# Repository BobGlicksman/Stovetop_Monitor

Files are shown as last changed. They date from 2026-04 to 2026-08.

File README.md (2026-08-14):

# Stovetop_Monitor.
## Overview.
The Stovetop Monitor project provides standoff, non-invasive monitoring of a stovetop with algorithms that 
determine if one or more burners are left on unintentionally.  An infrared (IR) temperature sensor is used to detect, 
categorize and track the IR radiation from the stovetop.  

## Purpose.
A stovetop burner that is accidentally left on presents a fire hazard.  Busy/distracted people, as well as elderly people 
who are becoming forgetful, can accidentally leave a stovetop burner on, unattended.  In the worst case, this can lead to 
a fire hazard and burn down the house as well as risking lives.  In less than the worst case, it can lead to damage to 
the stove and/or cookware.

## Solution.
The Stovetop Monitor uses a Melexis MLX90614 IR temperature sensor to continuously monitor both the ambient air temperature 
and the IR temperature of the stovetop.  A custom designed 3D printed enclosure houses the sensor and associated electronics.
The electronics mount underneath a cabinet that is above and off to the side of the stovetop.  The enclosure mounts the IR
temperature sensor so that it looks down at the stovetop at a 45 degree angle.  The entire stovetop is within the sensor's
field of view.

A Particle Photon 2 WiFi enabled microcontroller reads and processes sensor data.  The algorithm attempts to categorize what
is happening on the stovetop as Normal (burners are off), Warming (one or more burners on low), Cooking (one or more burners
on medium - high), or Burning (unusually high IR temperature reading).  Each of these stovetop states has an associated timeout,
beyond which it is assumed that the stovetop has been left on unattended.  After a timeout, a visual and audible alarm sounds.  A
remote alarm on a smartphone may also be configured using the Particle Cloud, Particle Webhooks and Pushover app capabilities.
An Android smartphone app is also included with this project, allowing a user to remotely monitor the status of their stovetop
an the ability to remotely reset any alarm in process.

See the "Stovetop_Monitor_Overview_and_Theory_of_Operation" document in this Repository for further details.

## Contents of this Repository.
### Top Level.
- "README.md": this document.
- "Terms_of_Use_License_and_Disclaimer":  You must agree to the contents of this document in order to use the material
    in this Repository.
- "Stovetop_Monitor_Overview_and_Theory_of_Operation":  This document provides an overview of the project.  It contains
    the project requirements, architecture, and theory of operation.
### Documents Folder.
- "Stovetop_Monitor_Build_and_Install_Manual":  Instructions for building and installing the Stovetop Monitor hardware
    and software.
- "Stovetop_Monitor_User_Manual":  Instructions for using the Stovetop Monitor, both locally and remotely.
### Hardware Folder.
- 3D CAD .stl files for the 3D printed enclosure and top mounting bracket.
- Fusion 360 .f3d file to allow modifying the enclosure design in Fusion 360 CAD software.
- MLX90614 IR temperature sensor datasheet.
- "A NOTE ABOUT PIEZO BUZZERS.txt": Options for the piezo buzzer that provides the audible alarm capability of the Stovetop Monitor.
### Software Folder.
#### AI2_App.
MIT App Inventor 2 source code and .apk installation file for the Android App that is part of this project.
#### StovetopMonitor.
Source code, libraries and helper files for the Photon 2 microcontroller.
#### Webhook.
JSON representation of the Particle Webhook for sending remote alarms using Pushover.

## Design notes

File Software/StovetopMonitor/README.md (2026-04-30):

# Stovetop_Test

This firmware project was created using [Particle Developer Tools](https://www.particle.io/developer-tools/) and is compatible with all [Particle Devices](https://www.particle.io/devices/).

Feel free to replace this README.md file with your own content, or keep it for reference.

## Table of Contents
- [Introduction](#introduction)
- [Prerequisites To Use This Template](#prerequisites-to-use-this-repository)
- [Getting Started](#getting-started)
- [Particle Firmware At A Glance](#particle-firmware-at-a-glance)
  - [Logging](#logging)
  - [Setup and Loop](#setup-and-loop)
  - [Delays and Timing](#delays-and-timing)
  - [Testing and Debugging](#testing-and-debugging)
  - [GitHub Actions (CI/CD)](#github-actions-cicd)
  - [OTA](#ota)
  - [Assets](#assets)
  - [Environment](#environment)
- [Support and Feedback](#support-and-feedback)
- [Version](#version)

## Introduction

For an in-depth understanding of this project template, please refer to our [documentation](https://docs.particle.io/firmware/best-practices/firmware-template/).

## Prerequisites To Use This Repository

To use this software/firmware on a device, you'll need:

- A [Particle Device](https://www.particle.io/devices/).
- Windows/Mac/Linux for building the software and flashing it to a device.
- [Particle Development Tools](https://docs.particle.io/getting-started/developer-tools/developer-tools/) installed and set up on your computer.
- Optionally, a nice cup of tea (and perhaps a biscuit).

## Getting Started

1. While not essential, we recommend running the [device setup process](https://setup.particle.io/) on your Particle device first. This ensures your device's firmware is up-to-date and you have a solid baseline to start from.

2. If you haven't already, open this project in Visual Studio Code (File -> Open Folder). Then [compile and flash](https://docs.particle.io/getting-started/developer-tools/workbench/#cloud-build-and-flash) your device. Ensure your device's USB port is connected to your computer.

3. Verify the device's operation by monitoring its logging output:
    - In Visual Studio Code with the Particle Plugin, open the [command palette](https://docs.particle.io/getting-started/developer-tools/workbench/#particle-commands) and choose "Particle: Serial Monitor".
    - Or, using the Particle CLI, execute:
    ```
    particle serial monitor --follow
    ```

4. Uncomment the code at the bottom of the cpp file in your src directory to publish to the Particle Cloud! Login to console.particle.io to view your devices events in real time.

5. Customize this project! For firmware details, see [Particle firmware](https://docs.particle.io/reference/device-os/api/introduction/getting-started/). For information on the project's directory structure, visit [this link](https://docs.particle.io/firmware/best-practices/firmware-template/#project-overview).

## Particle Firmware At A Glance

### Logging

The firmware includes a [logging library](https://docs.particle.io/reference/device-os/api/logging/logger-class/). You can display messages at different levels and filter them:

```
Log.trace("This is trace message");
Log.info("This is info message");
Log.warn("This is warn message");
Log.error("This is error message");
```

### Setup and Loop

Particle projects originate from the Wiring/Processing framework, which is based on C++. Typically, one-time setup functions are placed in `setup()`, and the main application runs from the `loop()` function.

For advanced scenarios, explore our [threading support](https://docs.particle.io/firmware/software-design/threading-explainer/).

### Delays and Timing

By default, the setup() and loop() functions are blocking whilst they run, meaning that if you put in a delay, your entire application will wait for that delay to finish before anything else can run. 

For techniques that allow you to run multiple tasks in parallel without creating threads, checkout the code example [here](https://docs.particle.io/firmware/best-practices/firmware-template/).

(Note: Although using `delay()` isn't recommended for best practices, it's acceptable for testing.)

### Testing and Debugging

For firmware testing and debugging guidance, check [this documentation](https://docs.particle.io/troubleshooting/guides/build-tools-troubleshooting/debugging-firmware-builds/).

### GitHub Actions (CI/CD)

This project provides a YAML file for GitHub, automating firmware compilation whenever changes are pushed. More details on [Particle GitHub Actions](https://docs.particle.io/firmware/best-practices/github-actions/) are available.

### OTA

To learn how to utilize Particle's OTA service for device updates, consult [this documentation](https://docs.particle.io/getting-started/cloud/ota-updates/).

Test OTA with the 'Particle: Cloud Flash' command in Visual Studio Code or the CLI command 'particle flash'!

This firmware supports binary assets in OTA packages, allowing the inclusion of audio, images, configurations, and external microcontroller firmware. More details are [here](https://docs.particle.io/reference/device-os/api/asset-ota/asset-ota/).

### Assets

To include assets in your OTA bundle, create an `assets` folder in your project root and place your files there. These can include audio files, images, configuration files, or firmware for external microcontrollers.

To enable asset OTA, uncomment the following line in `project.properties`:
```
assetOtaDir=assets
```

See the [Asset OTA documentation](https://docs.particle.io/reference/device-os/api/asset-ota) for more details.

### Environment

To bundle environment variables with your firmware, create an `env.json` file in your project root. Uncomment the following line in `project.properties` to enable it:
```
env=env.json
```

See the [Environment documentation](https://docs.particle.io/reference/device-os/api/environment) for more details.

## Support and Feedback

For support or feedback on this template or any Particle products, please join our [community](https://community.particle.io)!

## Version

Template version 1.0.3

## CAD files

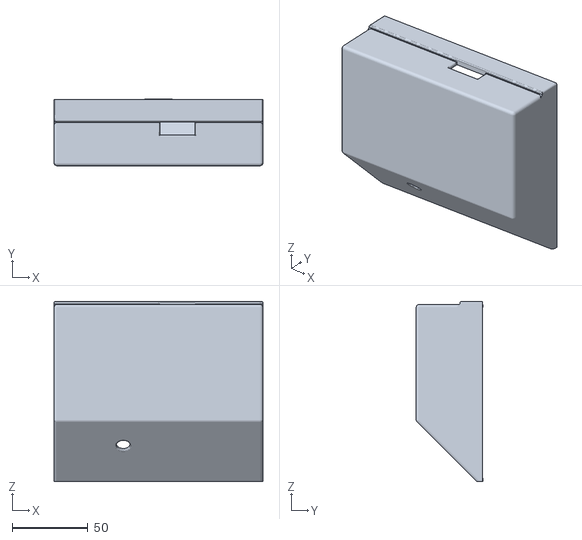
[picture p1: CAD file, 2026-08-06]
Hardware/stove monitor box.stl
138.0 x 44.0 x 119.0

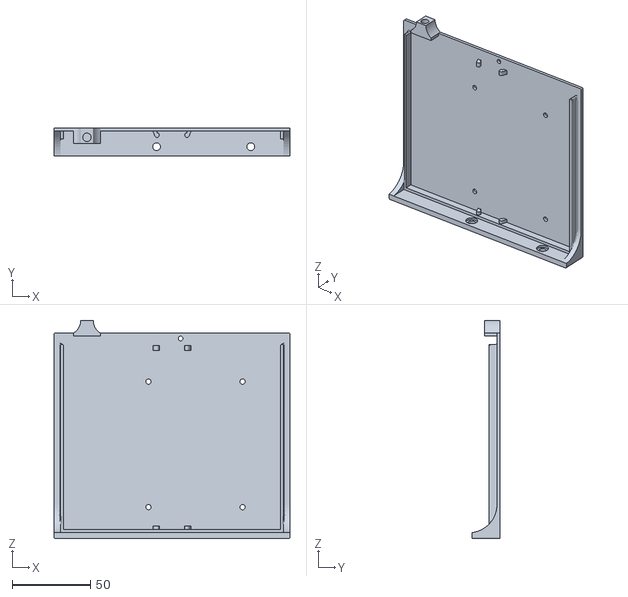
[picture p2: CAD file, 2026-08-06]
Hardware/stove monitor mount.stl
150.4 x 18.0 x 139.0

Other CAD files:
Hardware/stove monitor v34.f3d

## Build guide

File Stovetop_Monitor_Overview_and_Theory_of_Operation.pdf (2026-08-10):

# Stovetop Monitor Overview and Theory of Operation

By: Jim Schrempp and Bob Glicksman; v1.1, 8/10/2026

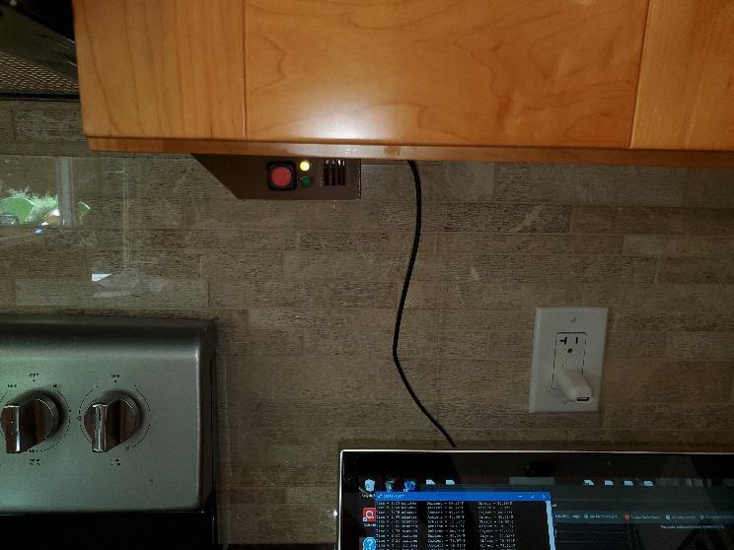
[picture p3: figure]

© 2026 Team Practical Projects, Bob Glicksman, and Jim Schrempp. All rights reserved.

NOTICE: Use of this document is subject to the terms of use described in the document
“Terms_of_Use_License_and_Disclai mer” that is included in this release package. This document can be found at:

https://github.com/TeamPracticalProjects/Stovetop_Monitor/tree/main/Documents/Terms_of_Use_License_and_Dis claimer.pdf

© 2026, Team Practical Projects, Jim Schrempp and Bob Glicksman; all rights reserved. Subject to “Terms of Use, License and Disclosure”

TABLE OF CONTENTS.

TABLE OF CONTENTS. | 1
DOCUMENT OVERVIEW. | 2
PROBLEM STATEMENT AND SOLUTION OVERVIEW. | 2
STOVETOP MONITOR SYSTEM OVERVIEW. | 3
Electronics. | 4
Particle Cloud. | 5
Pushover. | 5
Stovetop Monitor App. | 6
STOVETOP MONITOR THEORY OF OPERATION. | 6

DOCUMENT OVERVIEW.

This document provides an overview of the Stovetop Monitor project from Team Practical Projects. The Stovetop Monitor monitors the state of a stovetop and alarms if it senses that a burner is turned on for too long.

# PROBLEM STATEMENT AND SOLUTION

OVERVIEW.

A stovetop burner that is accidentally left on presents a fire hazard. Busy/distracted people, as well as elderly people who are becoming forgetful, can accidentally leave a stovetop burner on, unattended. In the worst case, this can lead to a fire hazard and burn down the house as well as risking lives. In less than the worst case, it can lead to damage to the stove and/or cookware.

There are few, if any, stovetop/ovens on the market that provide remote access via an app. In general, interconnected stoves have apps that can monitor and control an oven but do not have a similar capability vis-a-vis the stovetop burners. These apps are aimed at remote control of baking in the oven and it is assumed that cooking on the stovetop will always be attended.

Modern stovetop/ovens tend not to have mechanical controls. Rather, they are electronically controlled via an embedded microcontroller. This means that the status of the stovetop burners cannot be monitored nor can they be controlled remotely by hacking into electro-mechanical switches. An external solution - one that does not modify the stovetop/oven in any way - needs to be developed.

The Stovetop Monitor project provides standoff, non-invasive monitoring of a stovetop with algorithms that determine if one or more burners are left on unintentionally. An infrared (IR) temperature sensor is used to detect, categorize and track the IR radiation from the stovetop. The difference between the IR temperature measurement from the stovetop area and the ambient temperature is used to classify the current operation of the stovetop into:

- WARMing
- COOKing
- BURNing

Each of these stovetop states is pre-assigned a time limit above which it can be assumed to exceed normal stovetop operation. When the time limit is exceeded in any of these states, an ALARM is indicated and the user is notified to take action to attend to the situation. The temperature (temperature difference) and timeout thresholds that ultimately trigger alarms are contained in a separate file so that installation-specific values can be used. The Stovetop Monitor allows a computer running a serial monitor to attach and record IR and ambient temperature profiles for various test conditions in order to calibrate the system for the specific type of stovetop and sensor position for any specific installation.

The specific calibration values released with this project were empirically determined for an electric glasstop stove and a sensor that is mounted under a cabinet that is above and off to the right side of the stovetop. The sensor has a 90 degree field of view (FOV) and looks down at the stovetop at a 45 degree angle. The one sensor therefore covers the state of all of the burners on a stovetop. In addition to electric stovetops, this project should work well with gas burner stovetops. This project is not expected to be useful for induction stovetops, which turn off automatically when a pan is removed from a burner.

The standoff and non-invasive nature of this problem solution is, necessarily, imperfect. We have opted to err on the side of false positives, as the consequence of too many alarms is annoying but the consequences of missed alarm conditions can be very severe.

STOVETOP MONITOR SYSTEM OVERVIEW.

Figure 1 presents a system diagram for the Stovetop Monitor project.

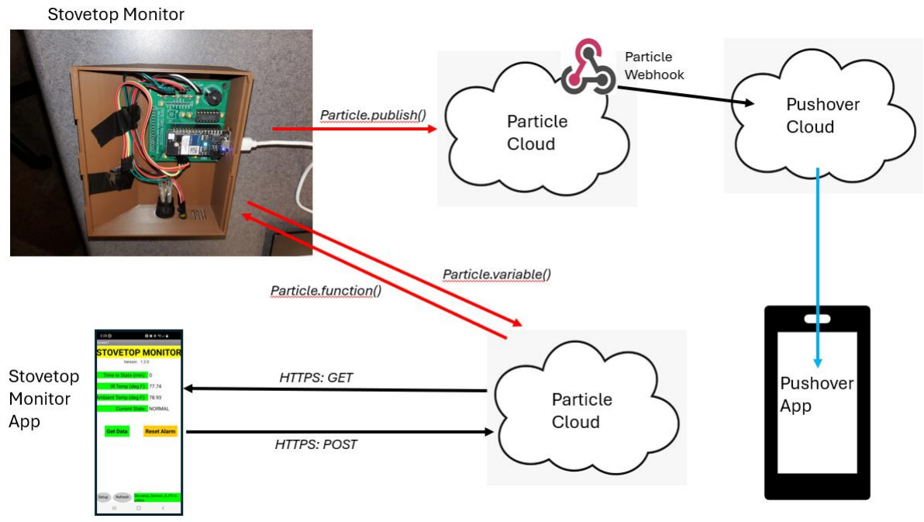
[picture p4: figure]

Figure 1. Stovetop Monitor System Overview.

The Stovetop Monitor electronics uses an IR temperature sensor to measure the infrared energy given off from the stovetop, as well as the ambient temperature at the sensor. A WiFi enabled microcontroller¹ uses these measurements to determine the state of the stovetop and to track the time in the current state. If the time in the current state exceeds a predetermined value, an alarm is generated.

Alarm events are published to the Particle Cloud. A webhook in the Particle Cloud subscribes to alarm events and uses the Pushover API to generate a push notification on the user’s smartphone.

An optional Android app uses the Particle Cloud API to read out the data from the electronics so that the user can determine the status of the Stovetop Monitor at any time. The App also allows the user to remotely reset any alarm that is in process.

Electronics.

The Stovetop Monitor electronics is based upon a Melexis MLX-60914 IR temperature sensor; see:
https://www.melexis.com/en/documents/documentation/datasheets/datasheet-mlx90614

We chose to use a breadboard friendly module that incorporates this sensor:

https://www.amazon.com/dp/B0B63K5V7T?ref=ppx_yo2ov_dt_b_fed_asin_title

The module includes the sensor itself, a low dropout voltage regulator, and I2C pullup resistors. The low dropout voltage regulator allows the module to operate with both 5 volt and 3.3 volt systems.

A Particle² Photon 2 microcontroller module forms the “brains” of the electronics. The Photon 2 is WiFi enabled and tightly integrated with the Particle Cloud. The Particle Cloud provides Internet connectivity to the electronics which is necessary for remote alarming and remote statusing of the system.

The sensor connects to the Photon 2 via the I2C bus. The electronics also contains level shifter circuitry that allows the Photon 2 to control a green, yellow and red LED and a piezo buzzer, and connects a pushbutton switch as a digital input to the Photon 2. The electronic components are mounted on the printed circuit board that was developed as part of an earlier Team practical Projects project, see:

https://github.com/TeamPracticalProjects/MN_ACL/tree/master/Hardware/PC_board

1 Particle Photon 2

2 Particle.io

Only part of the capability of this printed circuit board is used on this project. See the “Build and Install Manual” for this project for details.

The complete electronics are housed in a custom 3D printed enclosure with an accompanying 3D printed mounting bracket:

https://github.com/TeamPracticalProjects/Stovetop_Monitor/tree/main/Hardware

Particle Cloud.

The Particle Cloud provides Internet connectivity for this project:

- The firmware³
running on the Photon 2 publishes alarm events to the Particle Cloud. A custom webhook⁴
installed in the user’s Particle account subscribes to these event publications and uses the Pushover⁵ API to generate a push notification on the user’s smartphone. The Pushover notification serves as a remote alarm notification that is available to the user anywhere that they have smart phone connectivity.
- The firmware running on the Photon 2 exposes several global variables to the Particle Cloud, including the firmware version, the current stovetop state, the latest IR temperature reading, the latest ambient temperature reading, and the accumulated time in the current stovetop state.
- The firmware running on the Photon 2 provides remote calling of a function in the firmware that resets any alarm that is in process.

Pushover.

Pushover is a commercial service for adding push notifications to any smartphone. The user must install the Pushover app on their smartphone (available for both iOS and Android). The app requires a one time in-app fee of $5 and supports up to 10,000 push notifications per month at no additional cost. The Pushover app allows the user to select from a range of priority values and a large set of notification sounds.

3 https://github.com/TeamPracticalProjects/Stovetop_Monitor/tree/main/Software/StovetopMonitor

4 https://github.com/TeamPracticalProjects/Stovetop_Monitor/tree/main/Software/Webhook

5 https://pushover.net/

Stovetop Monitor App.

A Stovetop Monitor App⁶
is provided with this project. This App allows the user to monitor the status of the Stovetop Monitor and to remotely reset any alarm that is in process. The App is written in MIT App Inventor 2 has been built and tested for Android⁷ devices. The intention is that the user can respond to a remote alarm by viewing the status of the system in order to gain a better understanding of the nature of the alarm and the urgency of a response. However, the non-invasive nature of this project does not provide a means for the user to remotely control the stovetop itself. If a burner has been left on unintentionally, it will need to be manually turned off at the stovetop itself.

The user can, alternatively, use the Particle Console to monitor the stovetop and reset alarms. See the “Stovetop Monitor User Manual” for further details.

STOVETOP MONITOR THEORY OF OPERATION.

The firmware running on the Photon 2 microcontroller reads data from the Melexis sensor once every 15 seconds. This time interval was selected because of the large thermal lag of the stovetop. More frequent readings just add noise to the algorithm, while meaningful temperature changes occur more slowly.

Each reading from the sensor updates:
- The current IR temperature measurement.
- The current ambient sensor temperature measurement.

These readings are used to update the state of the system, per the state diagram shown in figure 2, below.

Note that the Melexis sensor occasionally and randomly returns an erroneous reading of 1899.59 degrees F on either the IR temperature or the ambient temperature. The reason for these erroneous readings is not known, but we think it is due to the fact that the Melexis sensor uses a special subset of the I2C protocol that powers down automatically and needs to occasionally wake-up when queried for new data. The firmware detects and disregards these erroneous readings.

6 https://github.com/TeamPracticalProjects/Stovetop_Monitor/tree/main/Software/AI2_App

7
In principle, this app can be built for iOS and deployed via the Apple App Store; However, we have not tested this deployment.

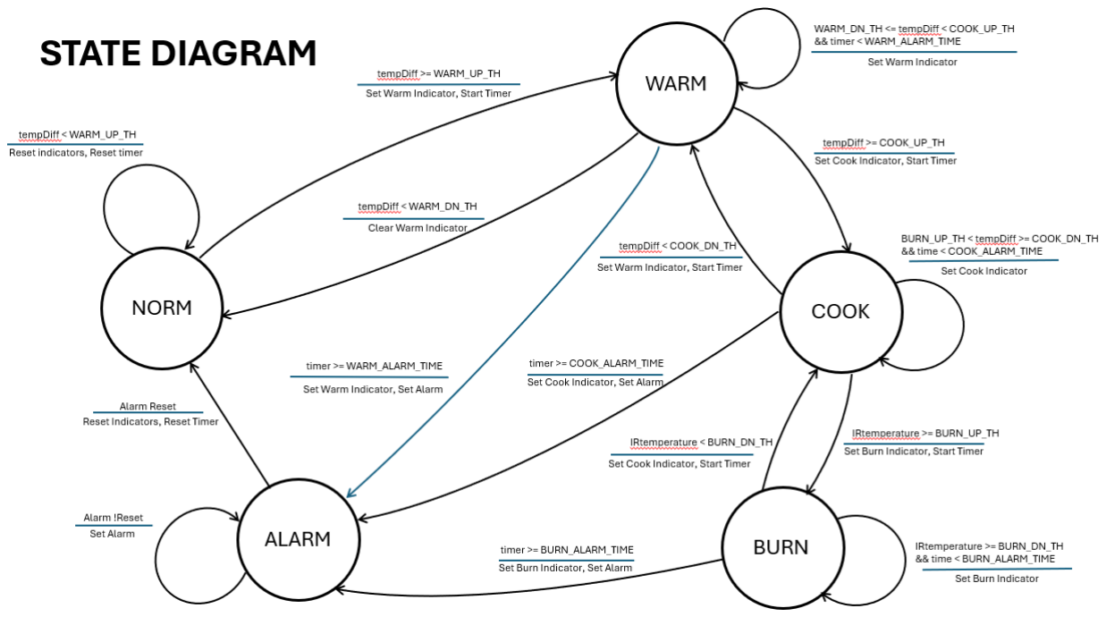
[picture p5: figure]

Figure 2. State Diagram.

Referring to figure 2: The system begins in the NORMal state. This state indicates that no burners are turned on. When no burners are turned on, the IR temperature reading is close to or below the sensor’s ambient temperature reading.

When the IR temperature minus the ambient temperature exceeds a WARM_UP_THreshold, the WARMing state is entered and a timer is initiated. Sensor readings continue as time in state accumulates. If the IR temperature minus the ambient temperature falls below the WARM_DN_THreshold, the timer resets and the system returns to the NORMal state. Conversely, if the IR temperature minus the ambient temperature exceeds a COOK_UP_THreshold, the timer resets and the COOKing state is entered. Finally, if the system stays in the WARMing state longer than a WARM_ALARM_TIME value, the ALARM state is entered and an alarm is generated.

The COOKing state operates similarly to the WARMing state, but with its own sets of thresholds for transitioning to either the BURNing state or back to the WARMing state. It also has its own timeout for generating an alarm.

The BURNing state operates similar to the WARMing state but is entered and exited based upon IR temperature only. The threshold for entering the BURNing state is an IR temperature reading that is abnormally high and only occurs when a burner is uncovered on a high setting or else when something is cooking and has “boiled down” to where it no longer absorbs heat. The BURNing state is abnormal and alarms after a short timeout period.

The state transition thresholds and timeouts were empirically determined by recording both “naked burner” data on each burner at various heat settings as well as capturing some actual cooking scenarios. Each stovetop, each sensor placement, and each cooking style will likely require different, individualized thresholds and timeouts. For this reason, these constants are stored in a separate header file in the program:

https://github.com/TeamPracticalProjects/Stovetop_Monitor/blob/main/Software/StovetopMonitor/src/ElectricStovetopConstants.h (https://github.com/TeamPracticalProjects/Stovetop_Monitor/blob/main/Software/StovetopMonitor/src/ElectricStovetopConstants.h)

The microcontroller firmware prints each set of sensor readings to the Serial port on the Photon 2 microcontroller. A computer running a serial monitor program can be used to record various cooking scenarios that can subsequently be analyzed to determine the best thresholds and timeouts for any specific installation.

Note that even in the best case, this non-invasive measurement algorithm is imperfect. We have chosen to err on the side of occasional false positive readings on the basis that false positives are an annoyance, whereas a missed alarm can be dangerous.

The Stovetop Monitor electronics has a green LED, a yellow LED and a red backlit pushbutton that are visible to the user. It also contains a piezo buzzer. The current state of the monitor is indicated as follows:

- GREEN LED on solid (other LEDs off): this is the NORMal state. Burners should all be off.
- YELLOW LED on solid (other LEDs off): this is the WARMing state.
- YELLOW LED flashing (other LEDs off): this is the COOKing state.
- RED LED (pushbutton backlight) on solid (other LEDs off): this is the BURNing state.
- RED LED (pushbutton backlight) flashing and Buzzer beeping (other LEDs off): this is the ALARM state. The ALARM state can only be exited by either pressing the red push button switch or by tapping the ALARM RESET button on the App.

The Android App can be used to remotely read out the status of the Stovetop Monitor. The App displays:

- The Current State of the Stovetop Monitor.
- The accumulated time in the current state (minutes).
- The latest IR Temperature reading (degrees F).
- The latest ambient temperature reading (degrees F).

The App also contains a button that can be tapped to remotely reset any alarm that is in process.

See the “Stovetop Monitor User Manual” for further details.

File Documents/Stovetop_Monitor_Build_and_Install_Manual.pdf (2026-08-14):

# Stovetop Monitor Build and Install Manual

By: Jim Schrempp and Bob Glicksman; v1.1, 8/13/2026


© 2026 Team Practical Projects, Bob Glicksman, and Jim Schrempp. All rights reserved.

NOTICE: Use of this document is subject to the terms of use described in the document
“Terms_of_Use_License_and_Disclai mer” that is included in this release package. This document can be found at:

https://github.com/TeamPracticalProjects/Stovetop_Monitor/tree/main/Documents/Terms_of_Use_License_and_Dis claimer.pdf

© 2026, Team Practical Projects, Jim Schrempp and Bob Glicksman; all rights reserved. Subject to “Terms of Use, License and Disclosure”

TABLE OF CONTENTS.

TABLE OF CONTENTS. | 0
DOCUMENT OVERVIEW. | 2
STOVETOP MONITOR HARDWARE. | 2
STOVETOP MONITOR ELECTRONICS. | 3
STOVETOP MONITOR ENCLOSURE ASSEMBLY. | 5
STOVETOP MONITOR SOFTWARE. | 9
STOVETOP MONITOR FIRMWARE. | 9
STOVETOP MONITOR WEBHOOK AND NOTIFICATION. | 10
STOVETOP MONITOR APP. | 11

DOCUMENT OVERVIEW.

This document describes the steps necessary to build and install the Stovetop Monitor from Team Practical Projects. The Stovetop Monitor monitors the state of a stovetop and alarms if it senses that a burner is turned on for too long.

The Stovetop Monitor consists of the following components:

- Hardware. The electronics and 3D printed enclosure that need to be mounted looking down at the stovetop being monitored.
- Firmware. The embedded software in the Particle Photon 2 microcontroller that is part of the electronic hardware.
- Mobile Phone Alarm. A Particle Webhook and the Pushover App are used to generate an alarm notification on the user’s mobile phone.
- Mobile Phone App. An App that can be installed on the user’s mobile phone allowing the user to monitor the state of the Stovetop Monitor remotely, and to reset an alarm that is in process.

See the “Overview and Theory of Operation Manual” for details about the system architecture and algorithm of the Stovetop Monitor project:

https://github.com/TeamPracticalProjects/Stovetop_Monitor/blob/main/Stovetop_Monitor_Overview_and_Theory_of_Operation.pdf (https://github.com/TeamPracticalProjects/Stovetop_Monitor/blob/main/Stovetop_Monitor_Overview_and_Theory_of_Operation.pdf)

Also see the “User Manual” for instructions describing local and remote control and status of the Stovetop Monitor:

https://github.com/TeamPracticalProjects/Stovetop_Monitor/blob/main/Stovetop_Monitor_Overview_and_Theory_of_Operation.pdf (https://github.com/TeamPracticalProjects/Stovetop_Monitor/blob/main/Stovetop_Monitor_Overview_and_Theory_of_Operation.pdf)

STOVETOP MONITOR HARDWARE.

The Stovetop Monitor hardware consists of a custom printed circuit board (PCB) and a custom 3D printed enclosure. The PCB holds the electronics, including the Particle Photon 2 microcontroller. The 3D printed enclosure has 2 parts – a Top cover that is for mounting the Stovetop Sensor underneath a cabinet, and the Enclosure body that holds all of the electronics, controls and indicators and the IR temperature sensor module.

STOVETOP MONITOR ELECTRONICS.

Most of the electronic components are mounted on a custom PCB. This PCB was originally developed for another Team Practical Projects project; see:

https://github.com/TeamPracticalProjects/MN_ACL/tree/master/Hardware/PC_board

Not all of the components on the original PCB design are required for this project. Figure 1, below, shows those components that are needed for the Stovetop Monitor and Figure 2 shows the components that should not be installed on the PCB for this project.

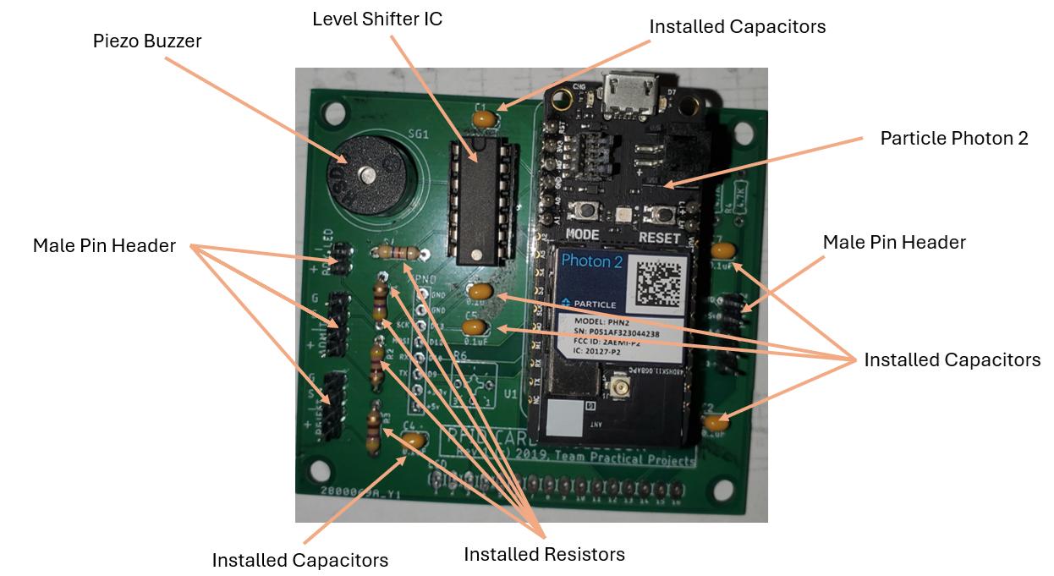
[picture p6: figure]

Figure 1. Electronics PCB – Installed Components.

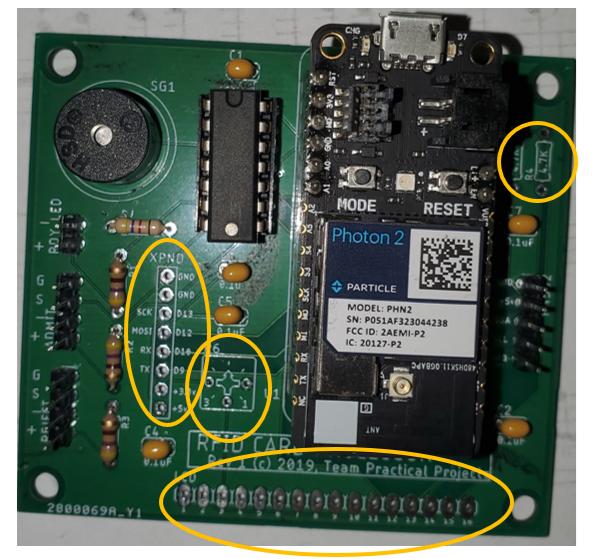
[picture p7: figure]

Figure 2. Components NOT Installed on PCB.

In particular, resistors R4 and R5 must not be installed on the PCB for this project, as the sensor module used already includes the I2C bus pull up resistors.

The PCB schematic is here:

https://github.com/TeamPracticalProjects/MN_ACL/blob/master/Hardware/PC_board/RFID_R1_Schematic.pdf (https://github.com/TeamPracticalProjects/MN_ACL/blob/master/Hardware/PC_board/RFID_R1_Schematic.pdf)

A parts list that includes the components for the PCB is here:

https://github.com/TeamPracticalProjects/MN_ACL/blob/master/Hardware/RFID_Station_Parts_List.pdf (https://github.com/TeamPracticalProjects/MN_ACL/blob/master/Hardware/RFID_Station_Parts_List.pdf)

NOTE: At the time of this writing, there is an issue with the Piezo Buzzer listed on this parts list (Adafruit P/N 1536). Adafruit is aware of the problem but it remains unresolved at this time. See the file “A Note About Piezo Buzzers.txt” for alternatives:

https://github.com/TeamPracticalProjects/MN_ACL/blob/master/Hardware/A%20NOTE%20ABOUT%20PIEZO%20BUZZERS.txt (https://github.com/TeamPracticalProjects/MN_ACL/blob/master/Hardware/A%20NOTE%20ABOUT%20PIEZO%20BUZZERS.txt)

In addition to the parts mounted on the PCB, the following additional electronic parts are to be mounted inside the enclosure and wired to the male pin header connectors on the PCB:

- Generic 5 mm green LED (plus 5 mm LED panel mounting hardware)
- Generic 5 mm yellow LED (plus 5 mm LED panel mounting hardware)
- Red Backlit Momentary Pushbutton Switch (https://www.adafruit.com/product/1439)
- IR Temperature Sensor Module: (https://www.amazon.com/dp/B0B63K5V7T?ref=ppx_yo2ov_dt_b_fed_asin_title)

Note that the IR Temperature Sensor module comes with straight pin headers, but we have chosen to solder on 90 degree right angle pin headers to make the cabling a little neater.

STOVETOP MONITOR ENCLOSURE ASSEMBLY.

The Stovetop Monitor Enclosure consists of two 3D printed parts:

The Enclosure, shown in figure 3, below, houses all of the electronics. The 3D CAD file (.stl format) can be found in the “Hardware” folder of this repository:

https://github.com/TeamPracticalProjects/Stovetop_Monitor/blob/main/Hardware/stove%20monitor%20box.stl (https://github.com/TeamPracticalProjects/Stovetop_Monitor/blob/main/Hardware/stove%20monitor%20box.stl)

The Enclosure is open but has tabs that engage with the Top cover. The Top piece has a number of screw holes in the top surface and in the right angle side, allowing for flexible mounting underneath a cabinet that overlooks the stovetop. The 3D CAD file (.stl format) can be found in the Hardware folder of this repository:

https://github.com/TeamPracticalProjects/Stovetop_Monitor/blob/main/Hardware/stove%20monitor%20mount.stl (https://github.com/TeamPracticalProjects/Stovetop_Monitor/blob/main/Hardware/stove%20monitor%20mount.stl)

These two files can be imported into any slicer program to produce G-code files for 3D printing. We printed these components at 0.2mm resolution in generic PLA, but PETG or ABS might be preferred if the Stovetop Monitor is located where it might be exposed to high heat.

All of the Stovetop Monitor components are assembled inside the Enclosure, as shown in figure
3. There are 4 standoffs that align with the 4 mounting holes on the printed circuit board that is described in the Stovetop Monitor Electronics section, above. M3 screws may be used to mount the printed circuit board securely into the Enclosure. The printed circuit board is positioned so that the micro USB connector on the Photon 2 microcontroller sticks through the slot in the rear of the Enclosure. A USB cable connected to the Photon 2’s USB port supplies power to the electronics and also provides access to serial port data. Serial port data may be collected and analyzed to customize the thresholds and timeouts in the Photon 2 firmware to optimize the Stovetop Monitor performance to a specific installation and routine cooking conditions.

The Enclosure has a 45 degree sloping side that is designed to hold the IR temperature sensor module. There is a hole in this side where the sensor itself protrudes through the enclosure. The 45 degree angle exists so that the sensor looks down at the stovetop and the sensor’s 90 degree field of view covers the entire stovetop. The IR temperature sensor module is held in place using ordinary electrical tape, as shown in figure 3.

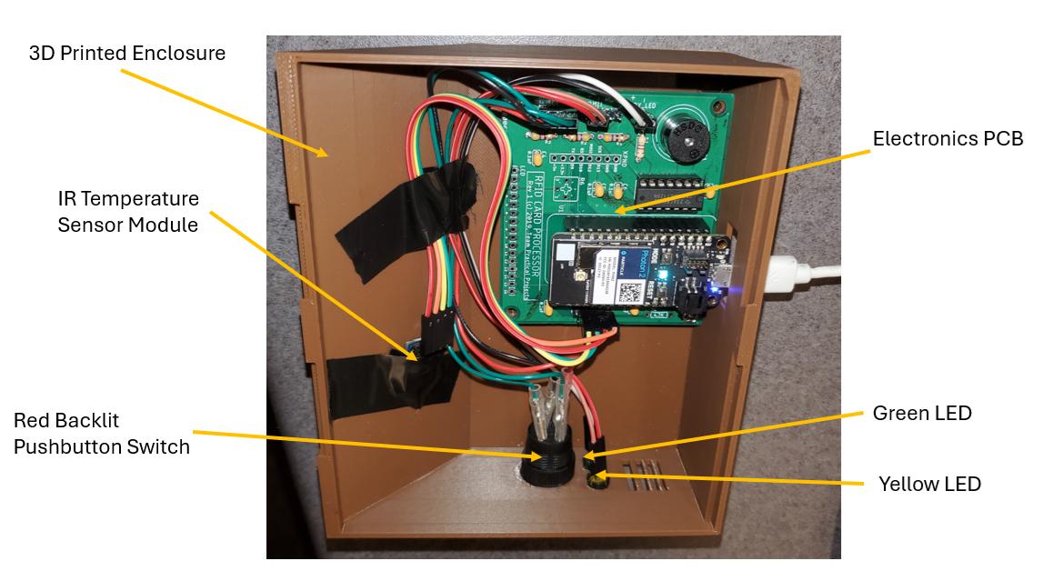
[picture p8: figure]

Figure 3. Assembled Enclosure.

The front side of the Enclosure has mounting holes for the three additional electronic components:

- Green LED
- Yellow LED
- Red backlit pushbutton switch

We recommend using standard 5 mm LED panel mounting hardware to mount the green and yellow LEDs to the enclosure. The red pushbutton switch mounts to the Enclosure using its own backset nut. Figure 4 is a front view of these components mounted in the Enclosure.

The front of the Enclosure also has grill slits that allow the buzzer sound to escape from the front of the Enclosure.

Standard female – female Dupont jumper cables can be used to connect the LEDs and the IR temperature sensor module pins to the male header pins on the printed circuit board, as shown in figure 3.

We made our own connector cables to connect the pushbutton switch’s spade lugs to the printed circuit board header pins. We used #26 awg stranded wire for these cables. We used 2.8 mm spade connectors for the pushbutton switch end of the wires and female Dupont crimp connectors for the PCB end of these wires. The crimp spade lugs can be obtained in the following kit:

https://www.adafruit.com/product/4748

The crimp Dupont female connectors and plastic connector bodies can be obtained from this kit:

https://www.amazon.com/dp/B0DRK17PTW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
0c9f99faf570&pf_rd_r=AVH4TYG53XQQ112G30G3&pd_rd_wg=vUs0M&pd_rd_r=b373 cd7d-91aa-4d6e-96fe-3ec430079ca3&ref_=sspa_dk_rhf_yoy_pt_sub&th=1 (https://www.amazon.com/dp/B0DRK17PTW?sp_csd=d2lkZ2V0TmFtZT1zcF9yaGZfeW95)

The crimping tool that comes with this kit can be used to crimp both the Dupont connector pins and the spade lugs.

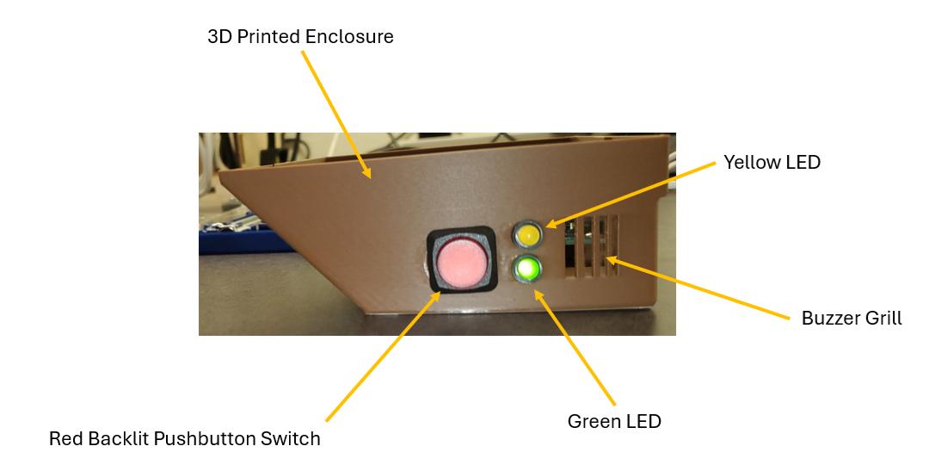
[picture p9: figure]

Figure 4. Assembled Enclosure Front Panel.

The parts that are mounted on the front of the Enclosure are connected to the PCB male pin headers are follows:

- Green LED: Connected to the “RDY LED” pins on the PCB. The anode (longer lead) is connected to the + pin on the PCB and the cathode (shorter lead) is connected to the – pin on the PCB.

- Yellow LED: Connected to the + and – pins of the “ADMIT” pins on the PCB. The anode (longer lead) is connected to the + pin on the PCB and the cathode (shorter lead) is connected to the – pin on the PCB. The S and G pins on the PCB are not connected.
- Red Pushbutton: The + and – lugs on the back of the pushbutton are connected to the + and – pins respectively of the “REJECT” pin field on the PCB. The unmarked (slightly larger) lugs on the back of the pushbutton are the switch leads and are connected to the S and G pins of the “REJECT” pin field on the PCB. The order of these switch pins does not matter.

The IR Temperature sensor module is connected to the field marked “PN532” on the PCB, as follows:

- VIN on the sensor to +5v on the PCB.
- GND on the sensor to GND on the PCB.
- SCL on the sensor to SCL on the PCB.
- SDA on the sensor to SDA on the PCB.
- The IRQ pin on the PCB is not connected.

When the 3D printed parts are available and assembly is complete, the Top cover piece is mounted underneath a cabinet so that the assembled Stovetop Monitor electronics will be off to one side of the stovetop with the sensor aimed down at the stovetop from a 45 degree angle. After mounting the Top cover to the underside of the cabinet, the assembled Enclosure will affix under the Top by placing it up to and slightly to the rear of the Top. The Enclosure is then slid forward until it engages with the tabs of the Top. The Enclosure will now be held securely to the Top.

A M4 threaded brass insert should be heat-set into the hole at the rear of the top piece. A long M4 machine screw should be inserted into a threaded hole at the rear of the Top piece, as shown in figure 5, below. This “keeper” screw should be tightened by hand so that it holds the Enclosure body securely to the Top bracket, ensuring that the Enclosure can’t slide backwards and disengage from the Top.

After completing mounting the Stovetop Monitor Electronics, a USB cable should be inserted into the micro USB connector protruding from the rear of the Enclosure. The other end of the USB cable is connected either to a USB power supply or to a laptop computer in order to power the Electronics and, optionally, collect serial data from it. See the “Stovetop Monitor User Manual” for instructions for obtaining and using serial data to customize the Stovetop Monitor to a specific installation, stove type, and cooking routines.

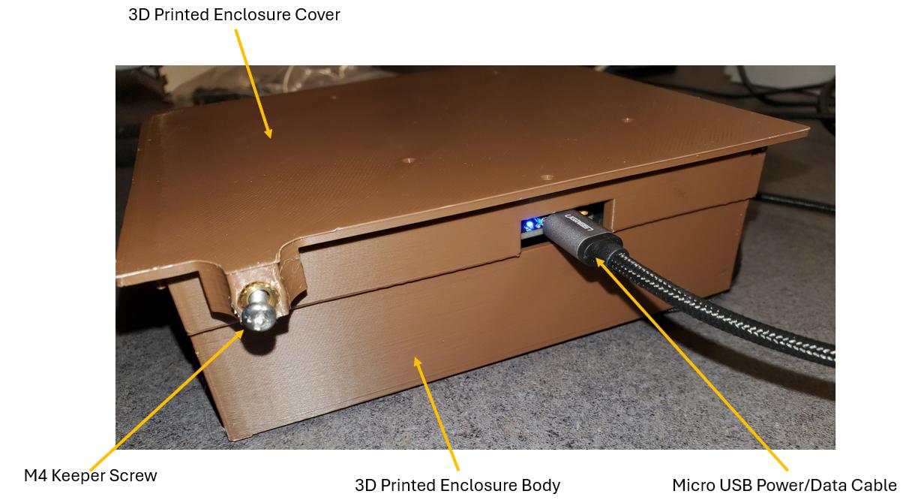
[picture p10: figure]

Figure 5. Assembled Enclosure with Top Bracket and Keeper Screw.

STOVETOP MONITOR SOFTWARE.

The Stovetop Monitor software components are open source. The source files are in the “Software” folder in this repository:

https://github.com/TeamPracticalProjects/Stovetop_Monitor/tree/main/Software

STOVETOP MONITOR FIRMWARE.

The Stovetop Monitor firmware is the software that is flashed to the Particle Photon 2 microcontroller that is part of the Stovetop Monitor Electronics. The source code is in this folder in this repository:

https://github.com/TeamPracticalProjects/Stovetop_Monitor/tree/main/Software/Stovetop Monitor (https://github.com/TeamPracticalProjects/Stovetop_Monitor/tree/main/Software/StovetopMonitor)

The main firmware is the “StovetopMonitor.ino” file. Note that the Adafruit library “Adafruit_MLX90614.h” is included and must be imported into the project in order to compile the “StovetopMonitor.ino” code.

In addition to the MLX90614 library, the following helper classes are included in “StovetopMonitor.ino” and must be included in the /src subfolder:

- BtnStatusClass (.h and .cpp): helper class to monitor the pushbutton in a non-blocking and debounced manner.
- LEDcontrolClass (.h and .cpp): helper class to provide non-blocking control of LEDs.
- ElectricStovetopConstants.h: included file that provides the thresholds and timeouts for the installation that this project was developed for.
- TestStovetopConstants.h: this file can be included in lieu of “ElectricStovetopConstants.h” for firmware testing purposes. The thresholds and timeouts are lowered to allow the firmware to be tested without high temperatures and long timeouts.

The thresholds and timeouts that are used by the firmware have been included in a separate file so that they can easily be changed to meet the needs of different stovetops, installation details and cooking scenarios. The serial port monitoring capability of the firmware is provided so that a user can record cooking scenarios on their specific installation and then analyze the data captured in order to tune the thresholds and timeouts to their own unique situation. See the “Stovetop Monitor User Manual” for further information.

STOVETOP MONITOR WEBHOOK AND NOTIFICATION.

The Stovetop Monitor user can choose to receive Stovetop alarms on one or more mobile devices. The Photon 2 firmware publishes alarm events to the Particle Cloud whenever the firmware transitions into the ALARM state.

A Webhook must be created in the user’s Particle account that subscribes to these events. The Webhook is created using the Particle Console in the “Integrations” section. A JSON representation of a Particle Webhook that fires off a Pushover¹ notification on a user’s mobile device is included in this repository:

https://github.com/TeamPracticalProjects/Stovetop_Monitor/blob/main/Software/Webhook/StoveTopAlarmWebhook.txt (https://github.com/TeamPracticalProjects/Stovetop_Monitor/blob/main/Software/Webhook/StoveTopAlarmWebhook.txt)

The user must install the Pushover App on their mobile device. This App is available for both Android and iOS. Note that use of this App requires a one time in-app purchase of $5 but does not require any recurring or ongoing fees.

The Webhook requires a user-specific “user access token” and a “pushover api token”. The “user access token” is created when a new user creates a Pushover account. The “pushover api token” is created on the Pushover website when the user creates an “app” on the Pushover cloud via the Pushover website. These tokens must be placed into the Particle Webhook where indicated by "<< your Pushover API token >>" and "<< your Pushover User access code >>".

1 Pushover.net

Refer to the Particle and Pushover on-line documentation for further details.

STOVETOP MONITOR APP.

An Android App is provided with this project. The user may install this App on an Android device and subsequently use the App to remotely status their Stovetop Monitor. Figure 7, below, shows the main screen of this App.

NOTE 1: This App is based upon a template that allows the user to log into their Particle account, obtain a list of Particle devices in their account, and select the Particle Photon 2 device that is used on their Stovetop Monitor. The App Template was developed on an earlier project, see: https://github.com/TeamPracticalProjects/Particle_App_Template. Particle changed the way a user remotely logs into their account in June 2024 and the App only works with Particle accounts that were established prior to this date. An App that is based upon an updated template is not available at this time. Users with newer Particle accounts can utilize the Particle Console to remotely monitor their stovetop. See the “User Manual” for details.

NOTE 2: This App was developed in MIT App Inventor 2. In theory, the App could be built to run on iOS platforms as well. However, this requires an Apple Developer Account and publication of the App code to the Apple App Store. We have not presently chosen to do this and we cannot certify that the App can be built and work on iOS devices. iOS users can utilize the Particle Console to remotely monitor their stovetop. The Pushover alert mechanism is not affected by this. See the “User Manual” for details.

In order to install the App on an Android device, the .apk file must be downloaded to the user’s Android device. This file is located in:

https://github.com/TeamPracticalProjects/Stovetop_Monitor/tree/main/Software/AI2_App

This folder also contains the MIT App Inventor 2 “source code” in the .aia file, in the spirit of open source.

After downloading “Stovetop_Monitor.apk” to the user’s Android device, the user must locate and tap on this file in order to install the App. Depending on the version of Android on the user’s device, some message about the App not being from a trusted source will appear. There will be an option to install the app anyway – choose this option to install the App on the Android device.

Tapping on the installed App will open the App and the screen will be similar to figure 7, below. However, the status indication at the bottom right of the screen will be red and indicate an error. This error occurs because the Photon 2 device in the user’s Stovetop Monitor must be selected before the App can be used to communicate with it. In order to select the device, tap the

“Setup” button at the lower left of the App home screen. This will take you to the setup screen, as shown in figure 6 below.

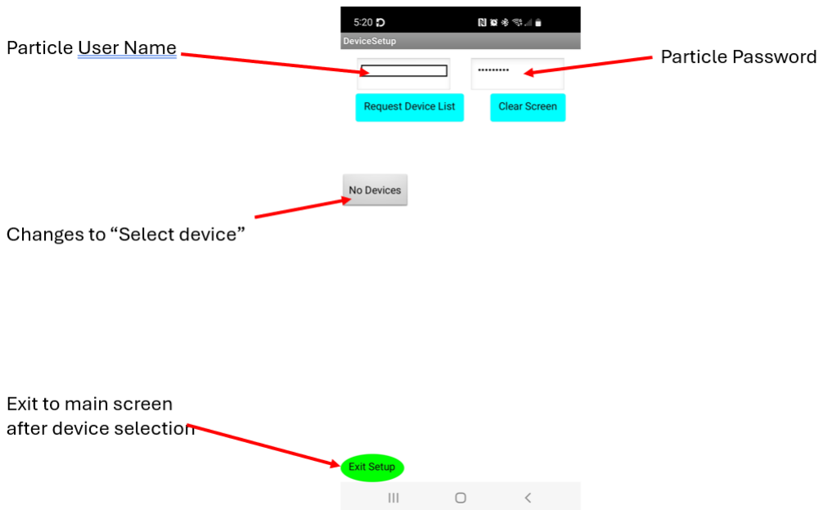
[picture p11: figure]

Figure 6. App Setup Screen.

Once in the setup screen of figure 6, type your Particle User Name and Particle Password into the text boxes indicated in figure 6. Then tap on “Request Device List”. If the login/password is correct, the button that says “No Devices” in figure 6 changes to “Select Device”. Tap on “Select Device” to view a popup list of all devices in the user’s Particle account. Tap on the Photon 2 device that is used on the Stovetop Monitor. Then tap on “Exit Setup” at the bottom left of the setup screen to return to the App home screen.

The App home screen should appear similar to figure 7, with the status at the bottom left being green and showing the selected Particle device to use with the App²

2 Note that the Stovetop Monitor Particle Photon 2 device must be powered and on-line in order for the status to shown green; otherwise, the status will be red and indicate an error trying to connect to the device.

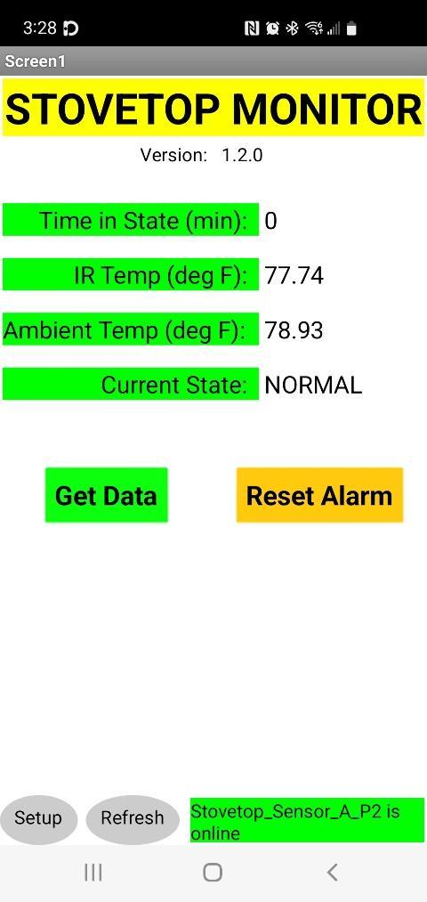
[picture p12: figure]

Figure 7. Stovetop Monitor App – After Device Selection.

See the “User Manual” for a description of using this App.

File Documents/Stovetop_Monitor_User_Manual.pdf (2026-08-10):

# Stovetop Monitor User Manual

By: Jim Schrempp and Bob Glicksman; v1.1, 8/10/2026


© 2026 Team Practical Projects, Bob Glicksman, and Jim Schrempp. All rights reserved.

NOTICE: Use of this document is subject to the terms of use described in the document
“Terms_of_Use_License_and_Disclai mer” that is included in this release package. This document can be found at:

https://github.com/TeamPracticalProjects/Stovetop_Monitor/tree/main/Documents/Terms_of_Use_License_and_Dis claimer.pdf

© 2026, Team Practical Projects, Jim Schrempp and Bob Glicksman; all rights reserved. Subject to “Terms of Use, License and Disclosure”

TABLE OF CONTENTS.

TABLE OF CONTENTS. | 1
DOCUMENT OVERVIEW. | 2
STOVETOP MONITOR LOCAL CONTROLS AND INDICATORS. | 2
STOVETOP MONITOR APP. | 5
STOVETOP MONITOR PARTICLE CONSOLE. | 6
STOVETOP CALIBRATION. | 8

DOCUMENT OVERVIEW.

This document describes how to use the Stovetop Monitor. The Stovetop Monitor monitors the state of a stovetop and alarms if it senses that a burner is turned on for too long. The Stovetop Monitor has local controls and indicators as well as an App for remote monitoring and alarm reset.

# STOVETOP MONITOR LOCAL CONTROLS AND

INDICATORS.

The front of the Stovetop Monitor enclosure is shown in figure 1, below. The following devices are available to the user:

- A green LED.
- A yellow LED.
- A red backlit pushbutton switch.
- A grill to conduct the sound of an internal buzzer out the front of the enclosure.

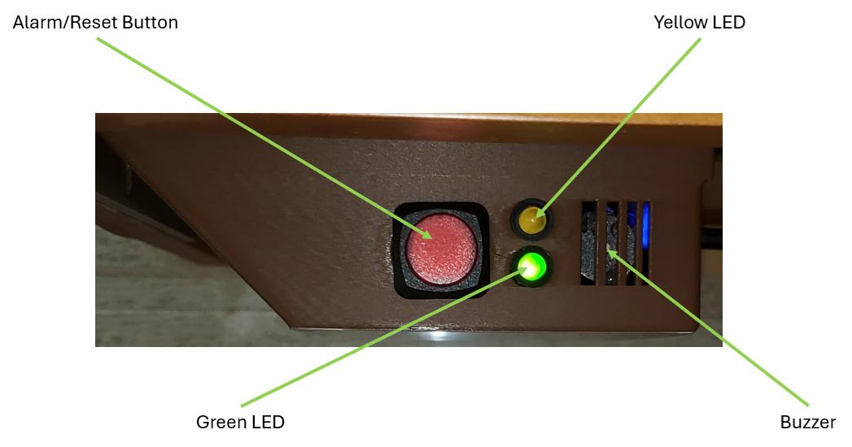
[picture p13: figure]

Figure 1. Stovetop Monitor Local Indicators and Control.

The following indications inform the user of the state of the stovetop being monitored:

1. Green LED on steadily: This indicates that the Stovetop Monitor is in the NORMal state. The NORMal state is when the IR temperature is near or below the ambient temperature, indicating that none of the burners are on.
2. Yellow LED on steadily: This indicates that the Stovetop Monitor is in the WARMing state. The WARMing state is when the IR temperature is higher than the ambient temperature by only a few degrees, indicating that one or more burners are on low for keeping food warm.
3. Yellow LED flashing: This indicates that the Stovetop Monitor is in the COOKing state. The COOKing state is when the IR temperature is higher than the ambient temperature by more than a few degrees, indicating that one or more burners are on medium / high for cooking food.
4. Red LED (backlight of the pushbutton) on steadily: This indicates that the Stovetop Monitor is in the BURNing state. The BURNing state is when the IR temperature is higher than normal for cooking, indicating that one or more burners are on medium /high and uncovered or else that one or more burners are on medium / high and the food has boiled down to where it is starting to burn. This is an abnormal condition and must be rectified within a few minutes or the alarm will be triggered.
5. Red LED (backlight of the pushbutton) flashing and Buzzer beeping: This indicates that the Stovetop Monitor has timed out in either the WARMing, COOKing, or BURNing state and an alarm condition exists. The alarm condition will persist until the user clears the alarm.

Each of the WARMing, COOKing, and BURNing states has a timeout. If the timeout expires while in one of these states, an alarm is generated and the alarm must be reset manually. The user can reset the alarm in one of two ways:

- By pressing the red pushbutton.
- By tapping the “Reset Alarm” button on the App (see below).

The timeouts and the thresholds for transitioning between states are contained in the file:

https://github.com/TeamPracticalProjects/Stovetop_Monitor/blob/main/Software/StovetopMonitor/src/ElectricStovetopConstants.h (https://github.com/TeamPracticalProjects/Stovetop_Monitor/blob/main/Software/StovetopMonitor/src/ElectricStovetopConstants.h)

The threshold values contain a temperature difference between the measured probe temperature and the ambient temperature. Each state has two threshold values, one for moving up to the next higher state (e.g. WARMing to COOKing) and a separate value for moving down to the next lower state (e.g. COOKing to WARMing). The probe is remote and the reported temperature values can vary slightly over time. The two individual values are needed to prevent the Stovetop Monitor from bouncing back and forth between states due to these small variations.

The values in this file were empirically determined by recording and analyzing various cooking and warming sessions on a particular electric glasstop stove. The type of stove, the location of the sensor, and the user’s particular cooking styles will all influence the proper values to use in any particular installation. The Stovetop Monitor firmware writes timestamped values of ambient temperature and IR temperature to the serial port. Connecting the serial port to a computer running a serial monitor program allows the user to collect data about some cooking session which can be stored and subsequently analyzed to help the user develop installation specific timeouts and thresholds for their specific situation.

The following are the timeouts and thresholds that are supplied with this project release:

- WARM_UP_TH. If the IR temperature exceeds the ambient temperature by at least this amount, the Stovetop Monitor transitions from the NORMal state to the WARMing state. The value in the released firmware is 1.5 degrees F.
- COOK_UP_TH. If the IR temperature exceeds the ambient temperature by at least this amount, the Stovetop Monitor transitions from the WARMing state to the COOKing state. The value in the released firmware is 7.0 degrees F.
- BURN_UP_TH. If the IR temperature exceeds this value (regardless of ambient temperature), the Stovetop Monitor transitions from the COOKing state to the BURNing state. The value in the released firmware is 130.0 degrees F.
- WARM_DN_TH. If the IR temperature exceeds the ambient temperature by no more than this amount, the Stovetop Monitor transitions from the WARMing state to the NORMal state. The value in the released firmware is 1.0 degrees F.
- COOK_DN_TH. If the IR temperature exceeds the ambient temperature by no more than this amount, the Stovetop Monitor transitions from the COOKing state to the WARMing state. The value in the released firmware is 6.0 degrees F.
- BURN_DN_TH. If the IR temperature is less than this value (regardless of ambient temperature), the Stovetop Monitor transitions from the BURNing state to the COOKing state. The value in the released firmware is 125.0 degrees F.
- WARM_ALARM_TIME. If the Stovetop Monitor is in the WARMing state for longer than this time, it transitions to the ALARM state and an alarm is generated. The value in the released firmware is 65 minutes.
- COOK_ALARM_TIME. If the Stovetop Monitor is in the COOKing state for longer than this time, it transitions to the ALARM state and an alarm is generated. The value in the released firmware is 40 minutes.
- BURN_ALARM_TIME. If the Stovetop Monitor is in the BURNing state for longer than this time, it transitions to the ALARM state and an alarm is generated. The value in the released firmware is 5 minutes.

See the “Overview and Theory of Operation Manual” in this repository for further information about the operation of the Stovetop Monitor.

STOVETOP MONITOR APP.

A mobile App was developed as part of this project. This App allows the user to quickly determine the current state information about their Stovetop Monitor. Figure 2 shows the main screen of the App.

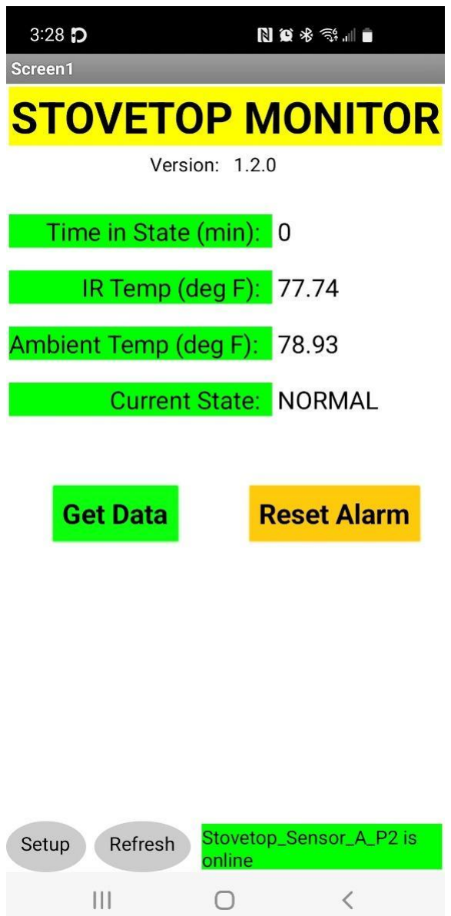
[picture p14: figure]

Figure 2. Stovetop Monitor Main App Screen.

When the App is opened and connected to a Stovetop Monitor device, all of the data shown on the main App screen (figure 2) is updated. The following data is displayed on this screen:

- Version. The version of the firmware that is running on the Stovetop Monitor.
- Time in State (min). The number of minutes that the Stovetop Monitor is in the current state. In the NORMal state, this value is always zero.
- IR Temp (deg F). The most recent IR temperature reading from the sensor.
- Ambient Temp (deg F). The most recent ambient temperature reading from the sensor.

- Current State. The current state of the Stovetop Monitor (NORM, WARM, COOK, BURN, ALARM).

The user can tap the Get Data button at any time to update the data displayed to the very latest values.

In the event that the Stovetop Monitor is in the ALARM state, tapping the Reset Alarm button will reset the current alarm and return the Stovetop Monitor to the NORMal state, from where it will advance according to the latest temperature readings.

This App is written in MIT App Inventor 2 and has been built and tested for Android devices only. See the “Stovetop Monitor Build and Install Manual” for installation and configuration information.

See the “Overview and Theory of Operation Manual” in this repository for further information about the operation of the Stovetop Monitor.

STOVETOP MONITOR PARTICLE CONSOLE.

The information and function of the Stovetop Monitor App is also available to the user via the Particle Console. The Particle Console is web-based and can be accessed from any device that runs a web browser:

https://console.particle.io/

The user must log in to their Particle Console with their Particle email and password. Once in the Particle Console, the user must select “My devices” and then select the Particle device (Photon 2) of their Stovetop Monitor from the list provided by Particle. The Particle Console then displays a status screen for that device. The lower right hand side of this screen contains the controls to obtain data from the device and to activate the Reset function, as depicted in figure 3, below.

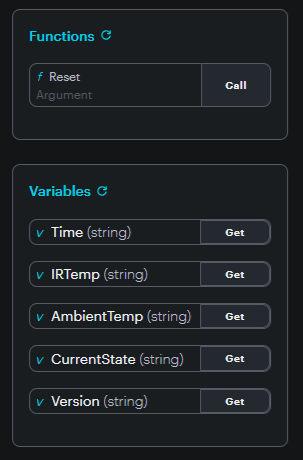
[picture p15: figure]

Figure 3. Particle Console Stovetop Monitor Data and Controls.

Referring to Figure 3: there is one function, called “Reset” listed under “Functions”. Clicking on “Call” is the same as tapping on “Reset Alarm” on the App. The Stovetop Monitor will reset the current alarm and return the Stovetop Monitor to the NORMal state, from where it will advance according to the latest temperature readings. No argument is needed for this function and anything typed into the “Argument” field will be ignored.

Referring to Figure 3: there are 5 “Variables” that are accessible from the Console. These are the same 5 variables as are displayed on the App screen when the “Get Data” button is tapped. However, each variable must be retrieved individually by tapping the “Get” button by each of the variable names.

See the “Overview and Theory of Operation Manual” in this repository for further information about the operation of the Stovetop Monitor.

STOVETOP CALIBRATION.

The threshold and timeout values released for this project were empirically determined by capturing various cooking sessions on a specific installation. The Stovetop Monitor firmware prints timestamped sensor data to the serial port continuously. A computer running a serial monitor program can record and save the data associated with specific cooking sessions for subsequent analysis and tuning of the threshold and timeout values for any particular installation. The file “ElectricStovetopConstants.h” can then be edited with installation specific values and saved under a different name in the same directory:

https://github.com/TeamPracticalProjects/Stovetop_Monitor/blob/main/Software/StovetopMonitor/src/ElectricStovetopConstants.h (https://github.com/TeamPracticalProjects/Stovetop_Monitor/blob/main/Software/StovetopMonitor/src/ElectricStovetopConstants.h)

Line 73 of the main firmware file can then be edited to #include the new calibration data file:

https://github.com/TeamPracticalProjects/Stovetop_Monitor/blob/main/Software/StovetopMonitor/src/StovetopMonitor.ino (https://github.com/TeamPracticalProjects/Stovetop_Monitor/blob/main/Software/StovetopMonitor/src/StovetopMonitor.ino)

Serial data from the firmware is written to the USB port of the Photon 2 microcontroller. This USB port is normally used just to power the Stovetop Monitor electronics. However, a laptop computer may be connected to this USB port and supply not only power but also receive serial data for recording and subsequent analysis. Any serial monitor program may be used for this purpose (e.g. Arduino serial monitor, VS Code serial monitor, Putty, etc.). The baud rate is 9600 baud.

Figure 4 shows a saved recording of serial data from the Stovetop Monitor using Putty. The Stovetop Monitor was reset when switching from a USB power supply to the laptop. Putty was opened after the Photon 2 reset and began running the code.

The message: “Stovetop Sensor Test … Ready for testing …” is printed during Setup(), then each new reading of data is printed on a timestamped line for as long as recording is desired. The recorded data was then stored in a file on the laptop and logged (with the test conditions under which it was obtained) for future analysis.

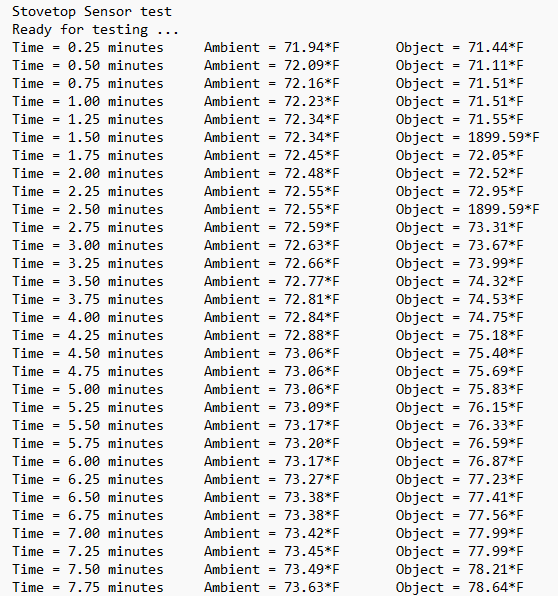
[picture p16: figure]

Figure 4. Serial Port Data from Stovetop Monitor.

Note that the recorded data is “raw” – unedited to remove the 1899.59 *F errors.

Once the data has been stored, it can be reviewed to understand the limits of the cooking session that was used to generate it:

- Peak IR temperature and peak ambient temperature captured during cooking.
- Time to peak temperature readings.
- Temperature range recorded during cooking interval.
- Time while cooking.
- Time at which heat was lowered or removed.
- Time too cool down to WARMing range (where IR temperature – ambient temperature is deemed to be too low for cooking).
- Time to cool down to NORMal range (where IR temperature is =< ambient temperature).

Note that there are a single set of thresholds and timeouts to cover all cooking scenarios. Therefore, a number of regular cooking sessions, as well as “contrived” scenarios (such as a

“naked burner” left on various heat settings), must be captured and analyzed before a reasonable set of constants can be properly determined.

We recommend that thresholds and timeouts be set to favor a reasonable number of false positive alarms, on the basis that false positives are annoying but false negatives can be dangerous!

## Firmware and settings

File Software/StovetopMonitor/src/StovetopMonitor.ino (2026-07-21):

/******************************************************************************************************
 StovetopMonitor:  This program monitors the infrared and ambient temperature of a stovetop
   in order to determine if the stovetop has been left on for too long and generates an alarm
   if so.  The program uses an MLX90614 IR temperature sensor to read the stovetop temperature
   from a distance.  It also measures the ambient temperature of the sensor.

   Experimental data was gathered in the spring of 2026 to determine the thresholds for the stovetop
   and ambient temperature readings that could indicate if one or more burners were tuned on for
   WARMing food, for COOKing food, or left open on high heat (BURNing).  Times in each state that e
   exceed normal operational times are also experimentally determined.  When a pre-determined time
   in any state exceed the time threshold for that state, the ALARM state is entered and the user is
   notified (both locally and remotely).  See the Concept Document for details:

    https://docs.google.com/document/d/18Uzl63lqLXmCHiYM6owl-rcvX6FZUQaka_lKGS37vmU/edit?usp=drive_link

    A Particle Photon 2 is used as the IoT processor for this project.  The Team practical
    Projects RFID Station pcb is used for this project; see:

    https://github.com/TeamPracticalProjects/MN_ACL/tree/master/Hardware/PC_board

    A Photon 2 is used in place of the depricated Argon and the pinouts are converted accordingly.
    The MLX90614 IR temerature sensor is connected to a Particle Photon 2 using the I2C bus.  A
    commercially available MLX90614 breakout board is used on this project:

    https://www.amazon.com/dp/B0B63K5V7T?ref=ppx_yo2ov_dt_b_fed_asin_title

    This breakout board houses the MLX90614 sensor, I2C bos pullup resistors, and a low droptout
    voltage regualator (so that it can rune from either 5 volts or 3.3 volts).  The sensor breakout board
    is connected to the Photon 2 using the I2C bus.  The Adafruit MLX90614 library is used to read
    data from the sensor.

    The pcb provides connections to the following components that are used to indicate the status
    of the monitored stovetop:

    - A green LED
    - A yellow LED
    - A red backlit pushbutton switch, containing the red LED and a button to manually reset an alarm.
    - A piezo buzzer

    Other components supported by the pcb are not used for this project:

    - 16x2 LCD display and its contrast pot
    - I2C bus pullup resistors (the MLX90614 breakout board has its own pullup resistors)

  Author:  Bob Glicksman
  Date: 7/06/26

  Version 1.2.0  7/21/26.  Minor bug fixes
  Version 1.1.0  7/19/26.  Made cloud variable names without spaces and converted to formatted strings.
  Version 1.0.0  7/16/26.  Initial release with operational constants
  Version 0.9.9  7/08/26. Preliminary release for testingWork in progress.


  (c) 2026 Bob Glicksman, Jim Schrempp, Team Practical Projects.
  All rights reserved.

********************************************************************************************************/

#define VER "1.2.0"

// Include Particle Device OS APIs
#include <Particle.h>

// Include MLX90614 library
#include <Adafruit_MLX90614.h>

// include the TPP LED and Button libraries
#include "LEDcontrolClass.h"
#include "BtnStatusClass.h"

// Include the constants for the Stovetop_Monitor project
// #include "TestStovetopConstants.h" // used for TESTING ONLY
#include "ElectricStovetopConstants.h" // constants for the electric stovetop

// Photon 2 pin definitions for this project
#define GREEN_LED D4
#define YELLOW_LED S4
#define RED_LED S3
#define BUZZER D2
#define ALARM_RESET D16

// define interval for data recording
#define RECORDING_INTERVAL 15000 // take data every 15 seconds

// instantiate the sensor
Adafruit_MLX90614 mlx = Adafruit_MLX90614();

// instantiate the LEDs and pushbutton
LEDcontrolClass greenLED(GREEN_LED);
LEDcontrolClass yellowLED(YELLOW_LED);
LEDcontrolClass redLED(RED_LED);
LEDcontrolClass buzzer(BUZZER);
BtnStatusClass resetBtn(ALARM_RESET);

// Global variables
double timeInState = 0.0;        // in minutes
double irTemperature = 0.0;      // in degrees F
double ambientTemperature = 0.0; // in degrees F

// Cloud Variables
String currentState = "Undefined"; // "Normal", "Warming", "Cooking", "Burning", "Alarm"
String version = VER;
String strTimeInState = "0";
String strIrTemperature = "undefined";
String strAmbientTemperature = "undefined";

//  Other globals
unsigned long loggingTimeMillis; // beginning millis() time for data sampling
enum State
{ // states of the system
    NORM,
    WARM,
    COOK,
    BURN,
    ALARM
};

State systemState; // The current state of the system - not the string to publish to the cloud!

/************************************************* */
// Functions

// Function to covert double to formatted string
String dtos(double val)
{
    String s = String::format("%.2f", val);
    return s;
}

// Cloud function to reset the system to the NORM state
int resetAlarm(String noString)
{
    systemState = NORM;
    return systemState;

} // end of resetAlarm()

// Function to refresh all of the LEDs and buzzer
void refreshAll()
{
    greenLED.refresh();
    yellowLED.refresh();
    redLED.refresh();
    buzzer.refresh();
} // end of refreshAll()

// Function to log data to the serial monitor
void printData(float time, double ir, double amb)
{
    Serial.print("Time = ");
    Serial.print(time);
    Serial.print(" minutes\t");
    Serial.print("Ambient = ");
    Serial.print(amb);
    Serial.print("*F\tObject = ");
    Serial.print(ir);
    Serial.println("*F");

} // end of printData()

/******************************************************************* */
void setup()
{
    // declare cloud variables and functions
    Particle.variable("Time", strTimeInState);
    Particle.variable("IRTemp", strIrTemperature);
    Particle.variable("AmbientTemp", strAmbientTemperature);
    Particle.variable("CurrentState", currentState);
    Particle.variable("Version", version);

    Particle.function("Reset", resetAlarm);

    // initializations
    Serial.begin(9600);
    greenLED.begin();
    yellowLED.begin();
    redLED.begin();
    buzzer.begin();
    resetBtn.begin();
    mlx.begin();

    // set flashing rates for this program
    greenLED.setRate(200);
    yellowLED.setRate(200);
    redLED.setRate(200);
    buzzer.setRate(200);

    // turn on the green LED until Photon 2 connected to the Particle cloud
    greenLED.on();
    yellowLED.off();
    redLED.off();
    buzzer.off();
    refreshAll();

    waitUntil(Particle.connected);

    // turn on all LEDs and turn the buzzer off - selftest
    greenLED.on();
    yellowLED.on();
    redLED.on();
    buzzer.on();
    refreshAll();

    // wait a few seconds to open the serial monitor
    delay(2000);

    // set the initial state of the system to NORM
    systemState = NORM;
    currentState = "Normal";
    Serial.println("Stovetop Monitor Data.");
    Serial.println("Ready ....");
    loggingTimeMillis = millis();

} // end of setup()

void loop()
{

    static unsigned long intervalMills;     // time interval for the next sensor reading
    static float intervalMinutes = 0.0f;    // time interval converted to minutes
    static double newIRtemp;                // IR value from the sensor - unfiltered
    static double newAmbtemp;               // Ambient value from the sensor - unfiltered
    static unsigned long baseTimeInState;   // millis() value when entering a new state
    static unsigned long millisTimeInState; // current time in the current state, in milliseconds

    intervalMills = millis() - loggingTimeMillis;

    // determine if it is time to sample new IR sensor data
    if (intervalMills >= RECORDING_INTERVAL)
    {
        intervalMinutes += ((float)(intervalMills) / 60000.0f);

        // read out the sensor and update global variables
        newIRtemp = mlx.readObjectTempF();
        newAmbtemp = mlx.readAmbientTempF();
        printData(intervalMinutes, newIRtemp, newAmbtemp); // print out the original data, even the errors

        //  test that readings are valid; if not valid, skip the update
        if ((newIRtemp < 1000.0) && (newAmbtemp < 1000.0))
        {
            irTemperature = newIRtemp;
            strIrTemperature = dtos(irTemperature);
            ambientTemperature = newAmbtemp;
            strAmbientTemperature = dtos(ambientTemperature);
        }

        loggingTimeMillis = millis();
    }

    // state machine for system behaviour
    switch (systemState)
    {
    case (NORM):

        // set normal state indicators
        greenLED.on();
        yellowLED.off();
        redLED.off();
        buzzer.off();

        // don't need to update time in state for NORMal state
        strTimeInState = "0";

        if ((irTemperature - ambientTemperature) >= WARM_UP_TH)
        {
            systemState = WARM;
            baseTimeInState = millis(); // initialize the time in the new state
        }
        else
        {
            // stay in the NORMal state
            systemState = NORM;
        }

        break;

    case (WARM):

        // set the warming state indicators
        greenLED.off();
        yellowLED.on();
        redLED.off();
        buzzer.off();

        // update the time in state
        millisTimeInState = millis() - baseTimeInState;
        timeInState = (double)(millisTimeInState) / 60000.0;
        strTimeInState = dtos(timeInState);

        if (timeInState >= WARM_ALARM_TIME)
        { // enter ALARM state
            Particle.publish("stovetopAlarm", "Alarm from WARM", PRIVATE);
            systemState = ALARM;
            baseTimeInState = millis(); // initialize the time in the new state
        }
        else
        { // no alarm, monitor the temperature to exit the state
            if ((irTemperature - ambientTemperature) >= COOK_UP_TH)
            { // enter the COOK state
                systemState = COOK;
                baseTimeInState = millis();
            }
            else
            {
                if ((irTemperature - ambientTemperature) <= WARM_DN_TH)
                { // back to the NORM state
                    systemState = NORM;
                    baseTimeInState = millis();
                }
                else
                { // we remain in the current state
                    systemState = WARM;
                }
            }
        }

        break;

    case (COOK):
        // set the cooking state indicators
        greenLED.off();
        yellowLED.flash();
        redLED.off();
        buzzer.off();

        // update the time in state
        millisTimeInState = millis() - baseTimeInState;
        timeInState = (double)(millisTimeInState) / 60000.0;
        strTimeInState = dtos(timeInState);

        if (timeInState >= COOK_ALARM_TIME)
        { // enter ALARM state
            Particle.publish("stovetopAlarm", "Alarm from COOK", PRIVATE);
            systemState = ALARM;
            baseTimeInState = millis(); // initialize the time in the new state
        }
        else
        { // no alarm, monitor the temperature to exit the state
            if ((irTemperature) >= BURN_UP_TH)
            { // enter the BURN state
                systemState = BURN;
                baseTimeInState = millis();
            }
            else
            {
                if ((irTemperature - ambientTemperature) <= COOK_DN_TH)
                { // back to the WARM state
                    systemState = WARM;
                    baseTimeInState = millis();
                }
                else
                { // we remain in the current state
                    systemState = COOK;
                }
            }
        }
        break;

    case (BURN):
        // set the burning state indicators
        greenLED.off();
        yellowLED.off();
        redLED.on();
        buzzer.off();

        // update the time in state
        millisTimeInState = millis() - baseTimeInState;
        timeInState = (double)(millisTimeInState) / 60000.0;
        strTimeInState = dtos(timeInState);

        if (timeInState >= BURN_ALARM_TIME)
        { // enter ALARM state
            Particle.publish("stovetopAlarm", "Alarm from BURN", PRIVATE);
            systemState = ALARM;
            baseTimeInState = millis(); // initialize the time in the new state
        }
        else
        { // no alarm, monitor the temperature to exit the state

            if ((irTemperature) <= BURN_DN_TH)
            { // back to the COOK state
                systemState = COOK;
                baseTimeInState = millis();
            }
            else
            { // we remain in the current state
                systemState = BURN;
            }
        }
        break;

    case (ALARM):
        // set the alarming state indicators
        greenLED.off();
        yellowLED.off();
        redLED.flash();
        buzzer.flash();

        // update the time in state
        millisTimeInState = millis() - baseTimeInState;
        timeInState = (double)(millisTimeInState) / 60000.0;
        strTimeInState = dtos(timeInState);

        // test for alarm reset button pressed
        if (resetBtn.isPressed() == true)
        {
            baseTimeInState = millis(); // initialize the time in the new state
            resetAlarm("noString");
        }
        else
        {
            systemState = ALARM;
        }
        break;

    default:                    // should never get here
        resetAlarm("noString"); // just return to the NORMal state
        break;
    }

    // update time in state

    // update current state as string
    switch (systemState)
    {
    case (NORM):
        currentState = "NORMAL";
        break;

    case (WARM):
        currentState = "WARMING";
        break;

    case (COOK):
        currentState = "COOKING";
        break;

    case (BURN):
        currentState = "BURNING";
        break;

    case (ALARM):
        currentState = "ALARM";
        break;

    default:
        currentState = "UNDEFINED";
        break;
    }

    // refresh LEDs and buzzer.
    refreshAll();

} // end of loop()

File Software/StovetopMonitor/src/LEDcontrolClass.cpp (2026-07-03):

/**************************************************************************************
 * LEDcontrolClass.  Library to control an LED or any device that can be turned on and
 *   off using digitalWrite(), e.g. LED, buzzer, etc.  Methods allow objects of this
 *   class to be turned on, tuend off, or flashed at a specifed rate.
 *
 *   the refresh() method must be called frequently in loop() in order to allow
 *   flashing to occur accurately.  Therefore, loop() code should be non-blocking.
 *
 * Author:  Bob Glicksma.
 * (c) 2026 by Bob Glicksman, Jim Schrempp, Team Practical Projects.  All rights reserved.
 *
 * Version 1.0. Initial release. 7/01/26
 *
 **************************************************************************************/

#include <LEDcontrolClass.h>

// constructor.  pin is the pin number to which the LED is connected.
LEDcontrolClass::LEDcontrolClass(int pin)
{
  _pin = pin;
  _currentState = OFF;
  _flashTime = DEFAULT_FLASH_TIME;
  _lastFlashTime = 0;
}

// begin() method.  Call in setup() to initialize the pin mode and set the LED to off.
void LEDcontrolClass::begin()
{
  pinMode(_pin, OUTPUT);
  _currentState = OFF;
}

void LEDcontrolClass::on()
{
  _currentState = ON;
}

void LEDcontrolClass::off()
{
  _currentState = OFF;
}

void LEDcontrolClass::flash()
{
  _currentState = FLASH;
}

void LEDcontrolClass::setRate(int flashTime)
{
  _flashTime = flashTime;
  refresh();
}

int LEDcontrolClass::getRate()
{
  return _flashTime;
}

void LEDcontrolClass::refresh()
{

  switch (_currentState)
  {
  case OFF:
    digitalWrite(_pin, LOW);
    break;
  case ON:
    digitalWrite(_pin, HIGH);
    break;
  case FLASH:
    if (millis() - _lastFlashTime >= _flashTime)
    {
      digitalWrite(_pin, !digitalRead(_pin));
      _lastFlashTime = millis();
    }
    break;

  default: // if unspecified in enum, defualt to flash
    if (millis() - _lastFlashTime >= _flashTime)
    {
      digitalWrite(_pin, !digitalRead(_pin));
      _lastFlashTime = millis();
    }
    break;
  }
}

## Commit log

2026-04-30 Basic data and program for testing
    [Steovetop_Monitor_Bracket_V2.3mf, Steovetop_Monitor_Bracket_V2.stl, Stovetop_Monitor_Bracket.3mf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]
2026-04-30 Deleted old hardware files
    Version 2 is the version of the bracket that is used.
    [Stovetop_Monitor_Bracket.3mf, Stovetop_Monitor_Bracket.stl]
2026-06-29 Update Stovetop_Test.cpp
    version 1.1. Added pin definitions and test code for LEDs for the RFID pcb.
2026-07-05 Version 0.9
    Almost working version. Need to add Particle.publish() to each state transition to ALARM; need to get reset button working.
2026-07-21 Update StovetopMonitor.ino
    version 1.2.0. Minor bug fixes:
    1. in Burn state, after temp falls below the BURN_DN_TH, go to the COOK state, not the WARM state.
    2. When resetting to NORM state, update the time so that NORM time is always zero.
    [StovetopMonitor.ino]
2026-07-21 Update StovetopMonitor.ino
    fix bug - in NORM state time in state should always be zero.
    [StovetopMonitor.ino]
2026-08-01 new 3D models
    [Steovetop_Monitor_Bracket_V2.3mf, Steovetop_Monitor_Bracket_V2.stl, stove monitor box.stl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]
